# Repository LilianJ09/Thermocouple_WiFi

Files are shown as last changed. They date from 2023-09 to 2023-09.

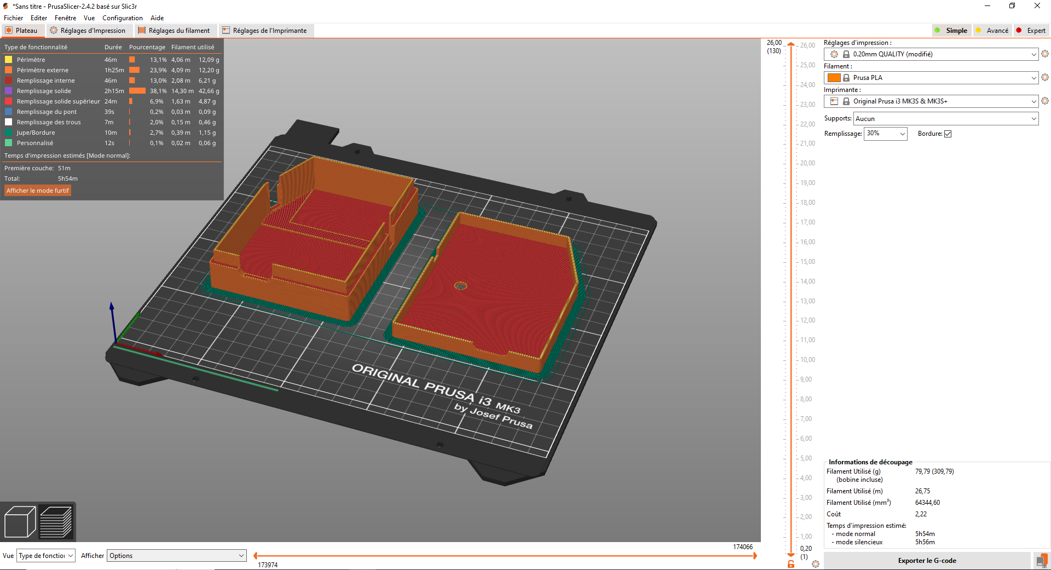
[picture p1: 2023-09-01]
CAD_modeling/prusa_slicer.PNG

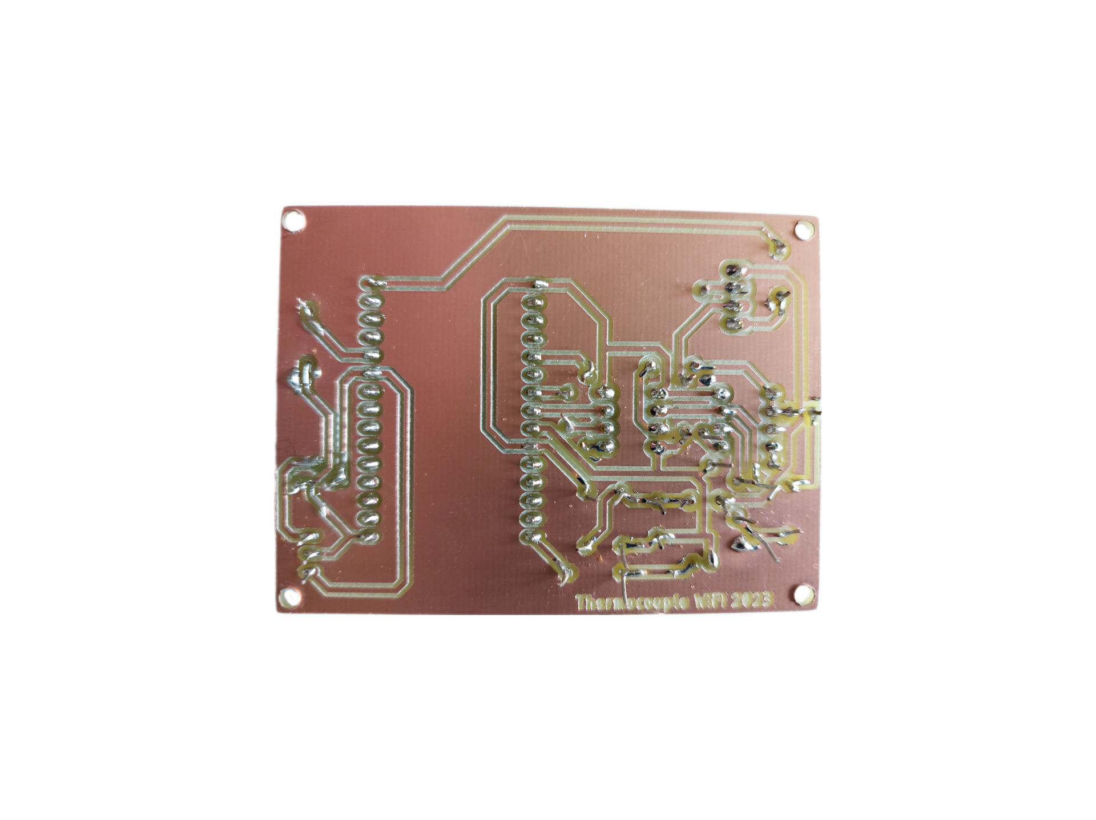
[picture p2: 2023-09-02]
Bank_pictures/Image-6.png

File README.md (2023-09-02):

# Thermocouple_WiFi
Developement of a kind K thermocouple with wireless data acquisition from an app.

The structure of the project is as follow :
  -Bank_pictures
  -CAD_modeling
  -App_thermocouple
    Throw the python file "Script_client-TCP" to start the App
  -Documents_produced

The components used are thoses : ESP8266 (nodeMCU), MCP3301, MCP6002 et LM335Z

JAOUANNE Lilian & GARCON Bastian

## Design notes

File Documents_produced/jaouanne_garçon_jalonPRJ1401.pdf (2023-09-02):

# PRJ1401 - THERMOCOUPLE

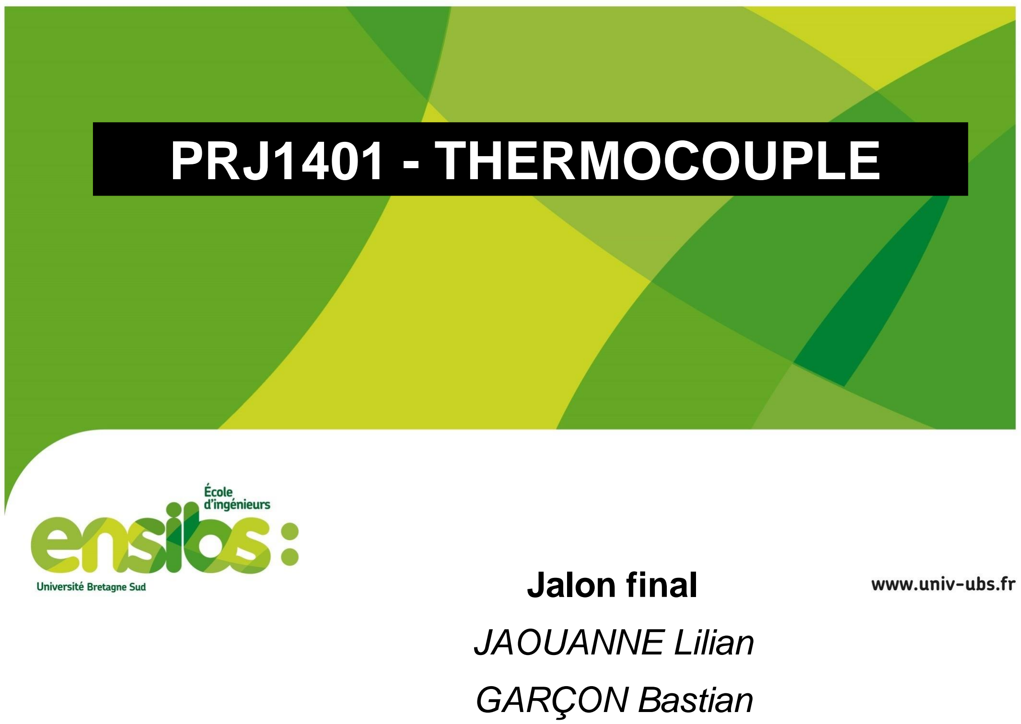
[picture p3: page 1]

Jalon final
JAOUANNE Lilian
GARÇON Bastian

# Cahier des charges

## - Plage de températures : -200 à 1200°C

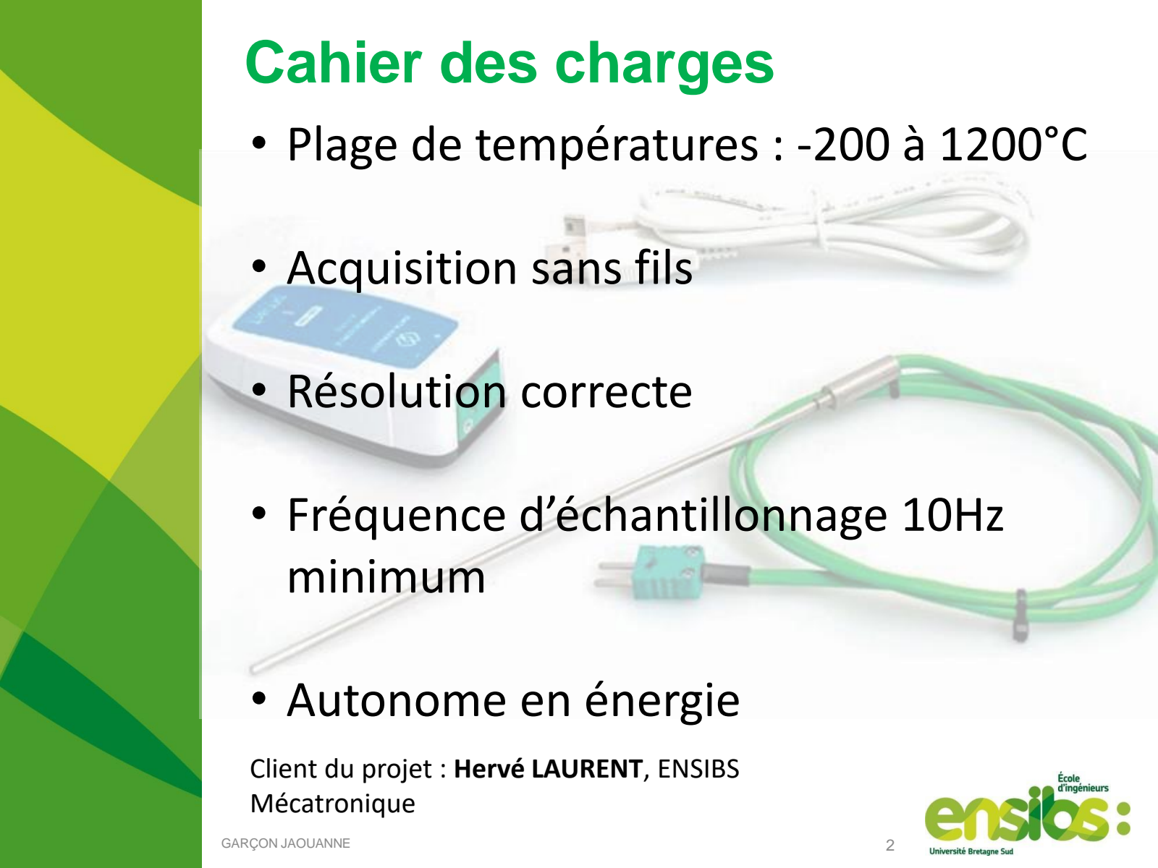
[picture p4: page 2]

GARÇON JAOUANNE | 2

Client du projet : Hervé LAURENT, ENSIBS Mécatronique

## - Acquisition sans fils

## - Résolution correcte

## - Fréquence d’échantillonnage 10Hz minimum

## - Autonome en énergie

# Où en étions nous ?

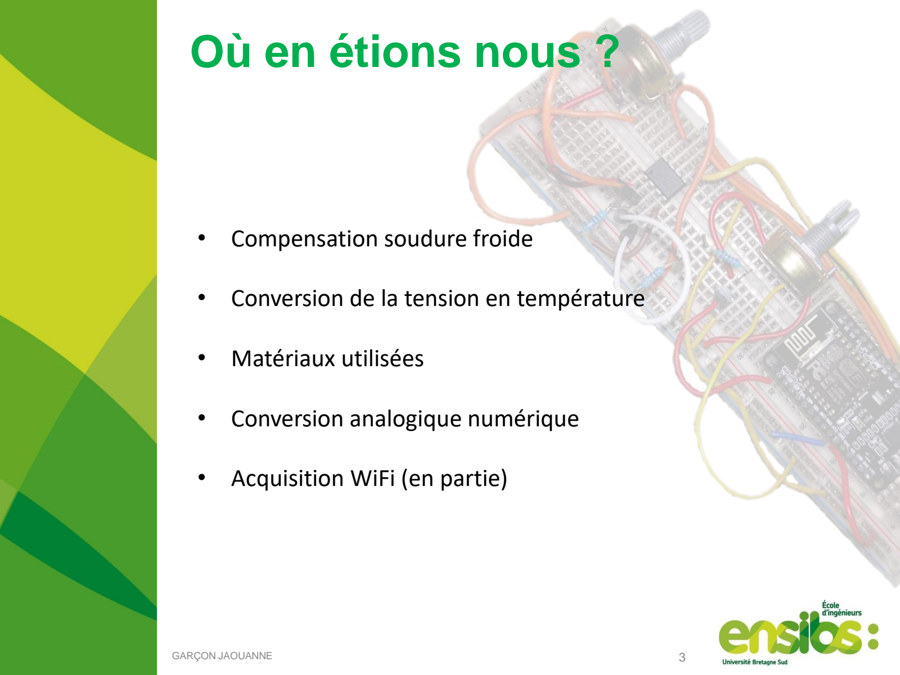
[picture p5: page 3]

- Compensation soudure froide
- Conversion de la tension en température
- Matériaux utilisées
- Conversion analogique numérique
- Acquisition WiFi (en partie)

# Ce que nous avons fait depuis

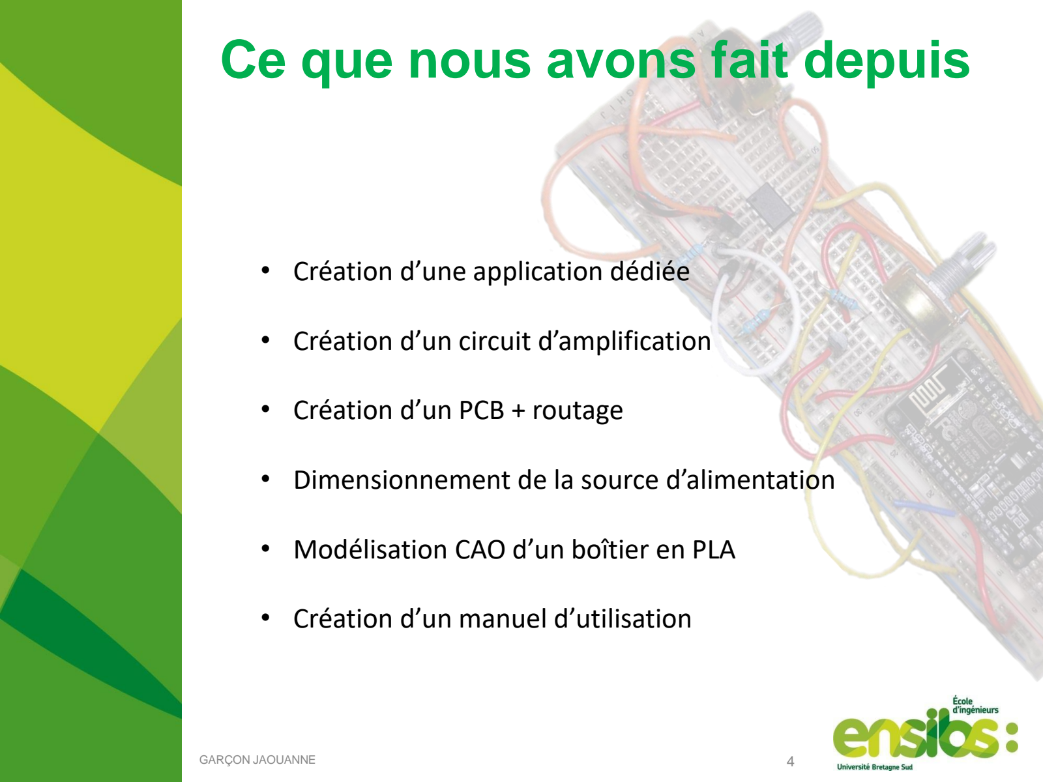
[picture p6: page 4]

- Création d’une application dédiée
- Création d’un circuit d’amplification
- Création d’un PCB + routage
- Dimensionnement de la source d’alimentation
- Modélisation CAO d’un boîtier en PLA
- Création d’un manuel d’utilisation

# Conversion tension / température

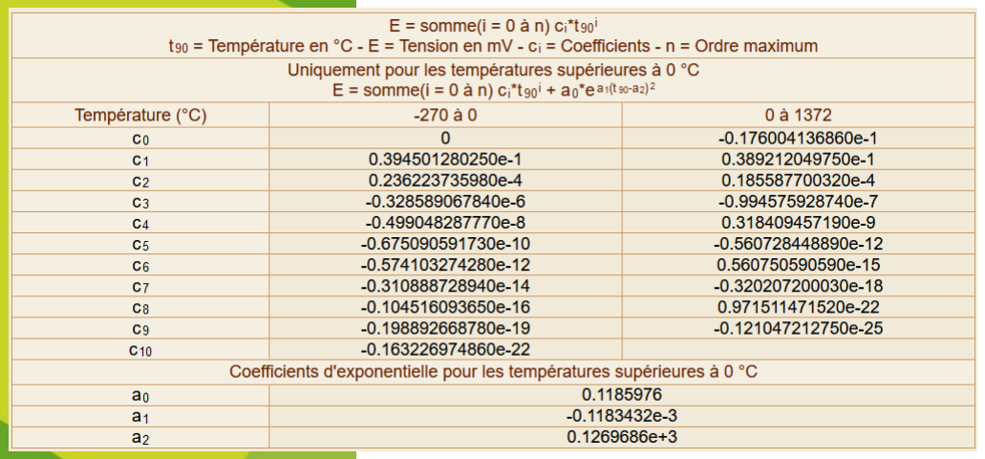
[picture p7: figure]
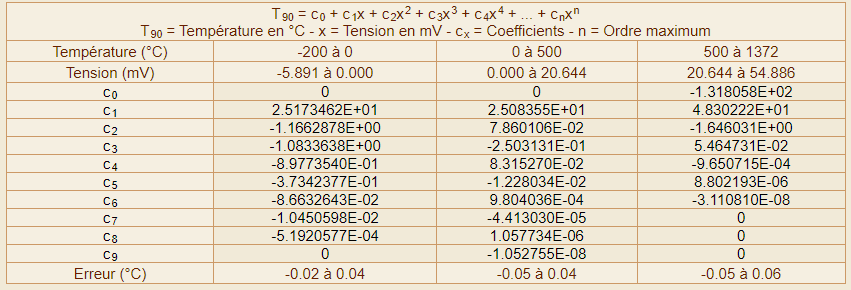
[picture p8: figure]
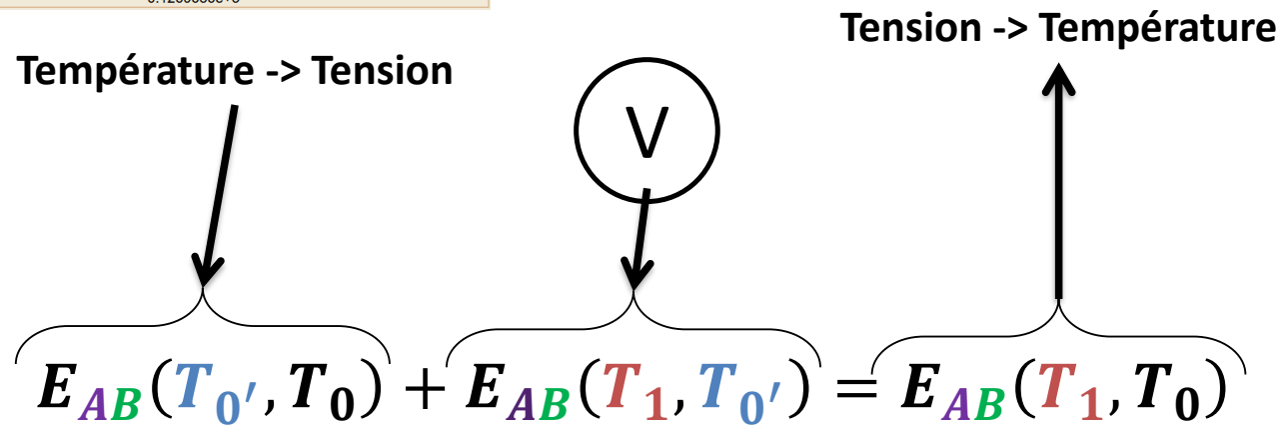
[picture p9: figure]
Température -> Tension; Tension -> Température; EAB T0; ′ , T0 + EAB T1, T0; = EAB T1, T0

# Matériaux utilisés

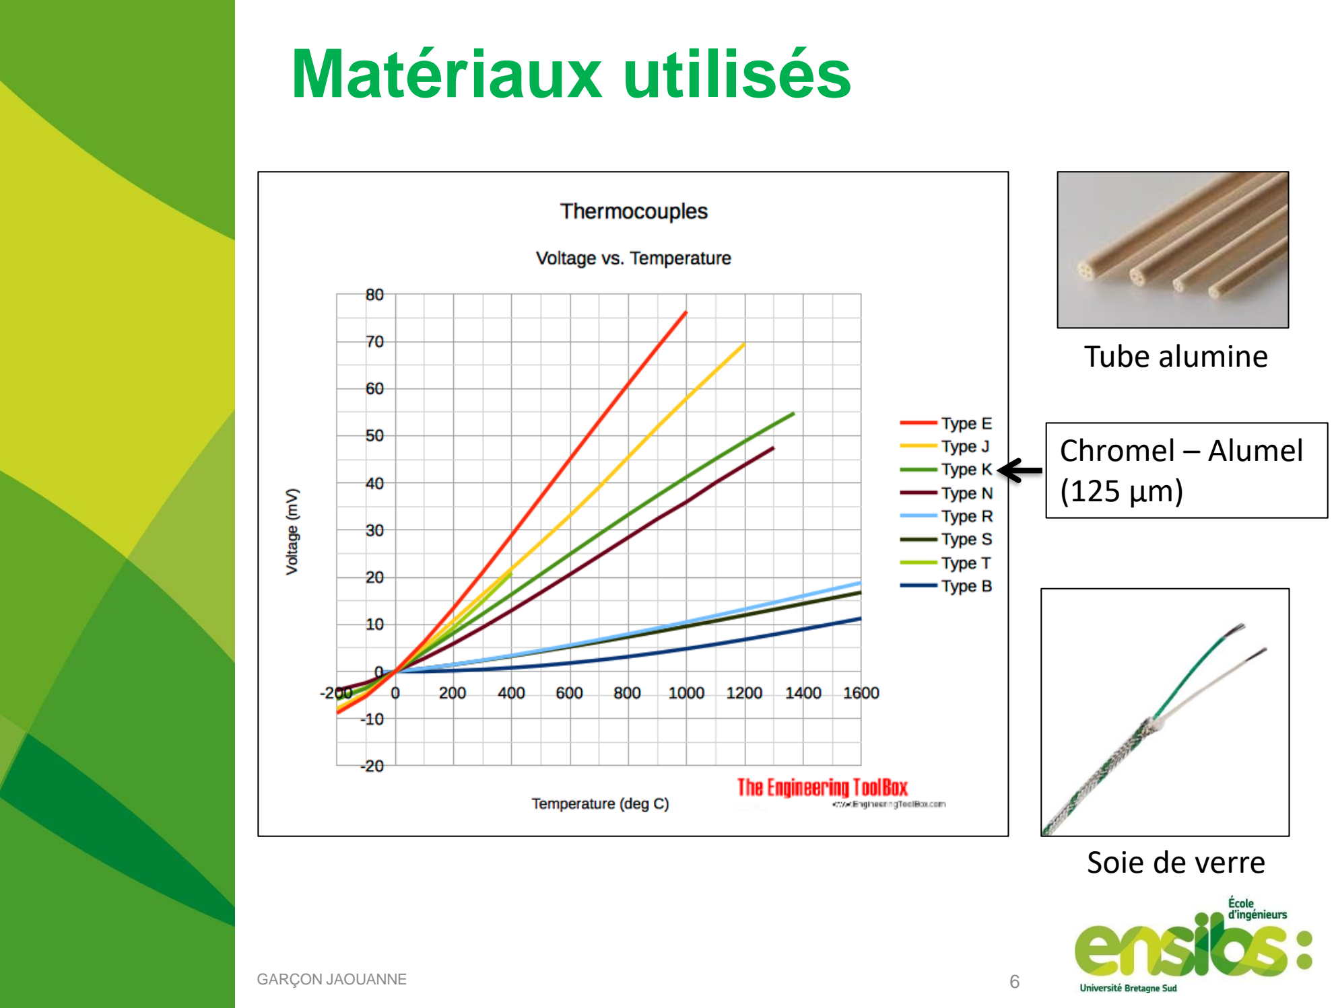
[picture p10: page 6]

Tube alumine

Soie de verre

Chromel – Alumel
(125 µm)

# Conversion analogique numérique MCP3301 13 bits

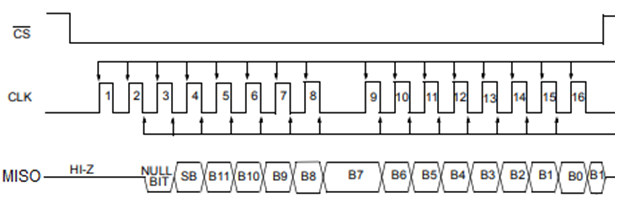
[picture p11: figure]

Mode de cadencement SPI : 0
- Polarité d’horloge (CPOL = 0) : Horloge en veille à l’état logique 0
- Phase d’horloge (CPHA = 0) : Cadencement des données sur le front montant

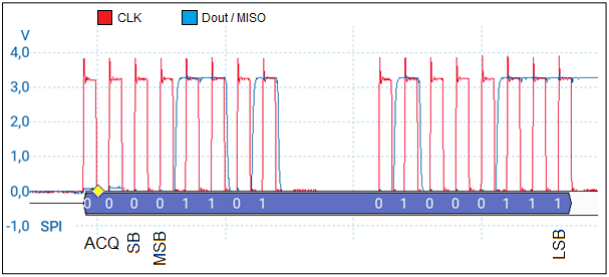
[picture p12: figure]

(0 0110 1010 0011)2S = 339910

Tension = 3399 × 1000 ×

Vref
4096

= 2738 mV, avec Vref = 3,3 V

# Conversion analogique numérique MCP3301 13 bits

# Acquisition WiFi

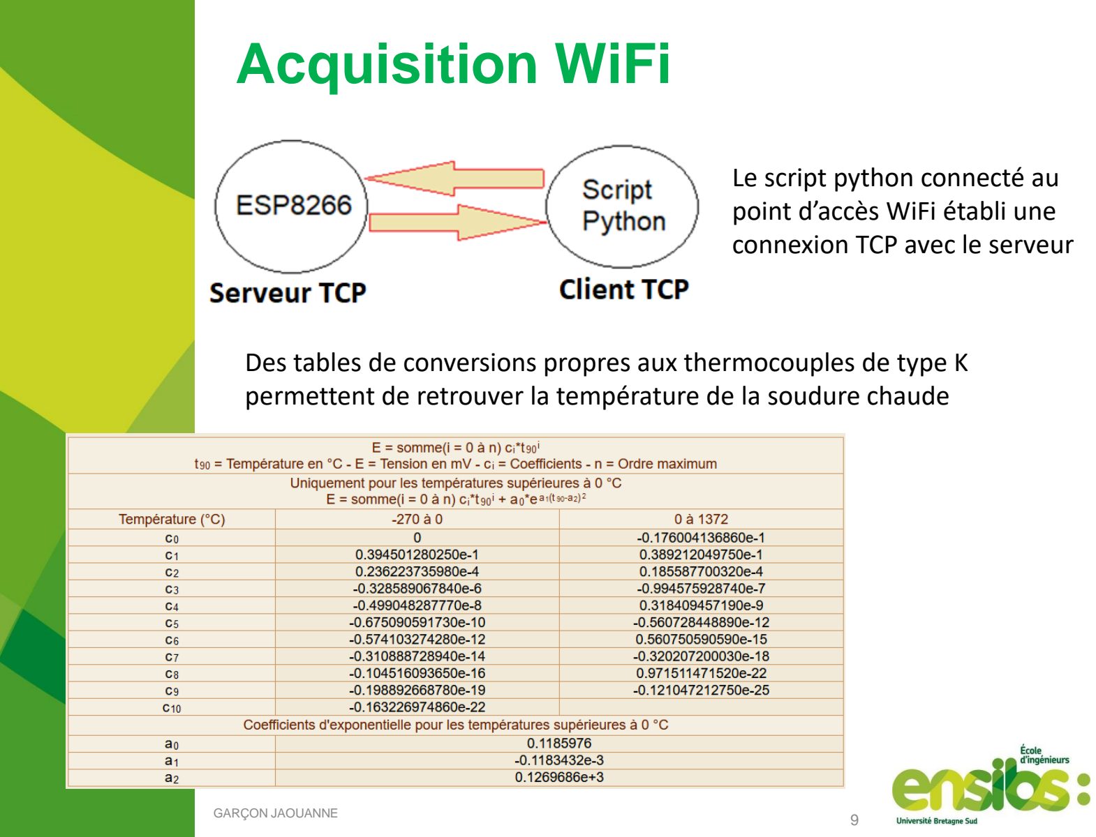
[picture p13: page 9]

Le script python connecté au point d’accès WiFi établi une connexion TCP avec le serveur

Des tables de conversions propres aux thermocouples de type K permettent de retrouver la température de la soudure chaude

# Application dédiée

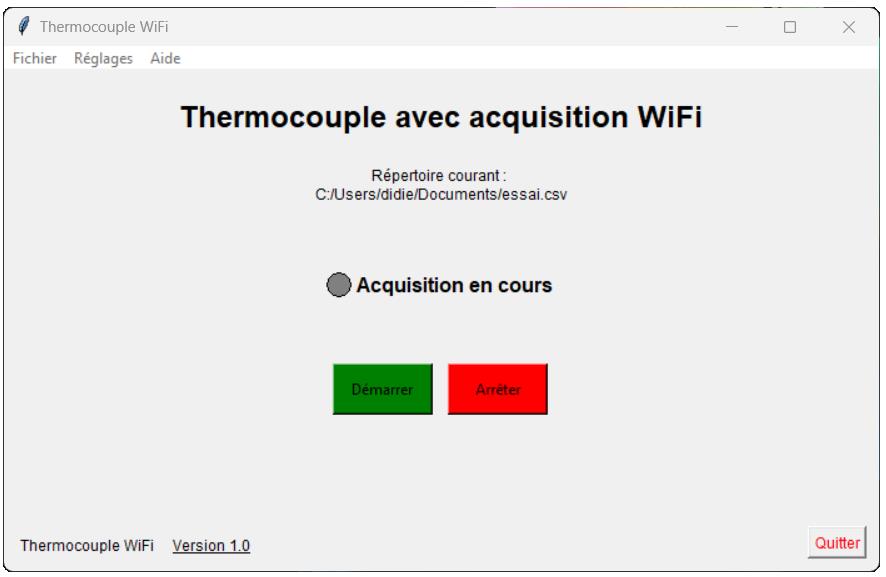
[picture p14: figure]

Icône application :

# Traitement des données

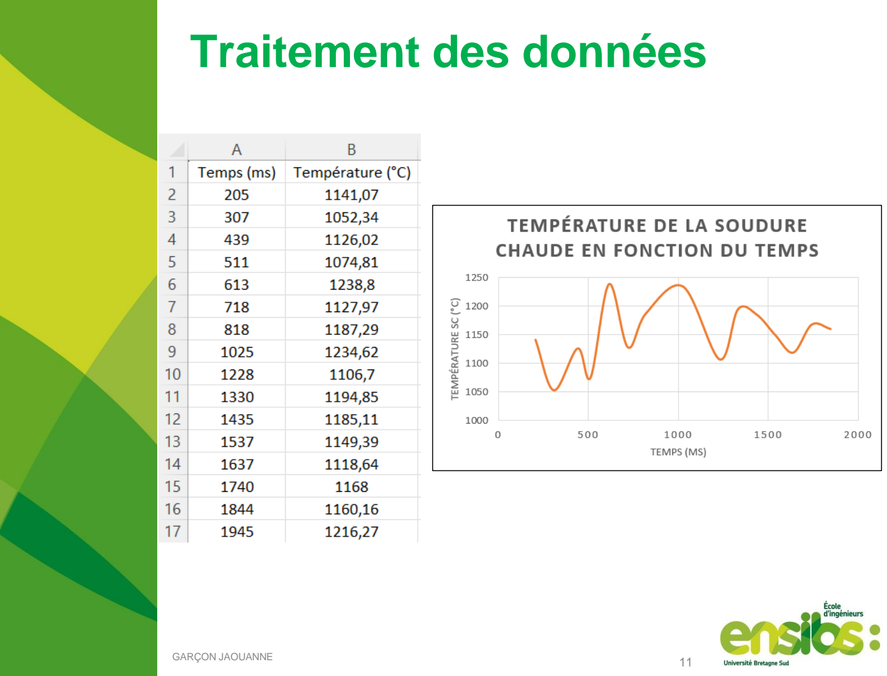
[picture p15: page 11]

# Amplification du signal MCP6002

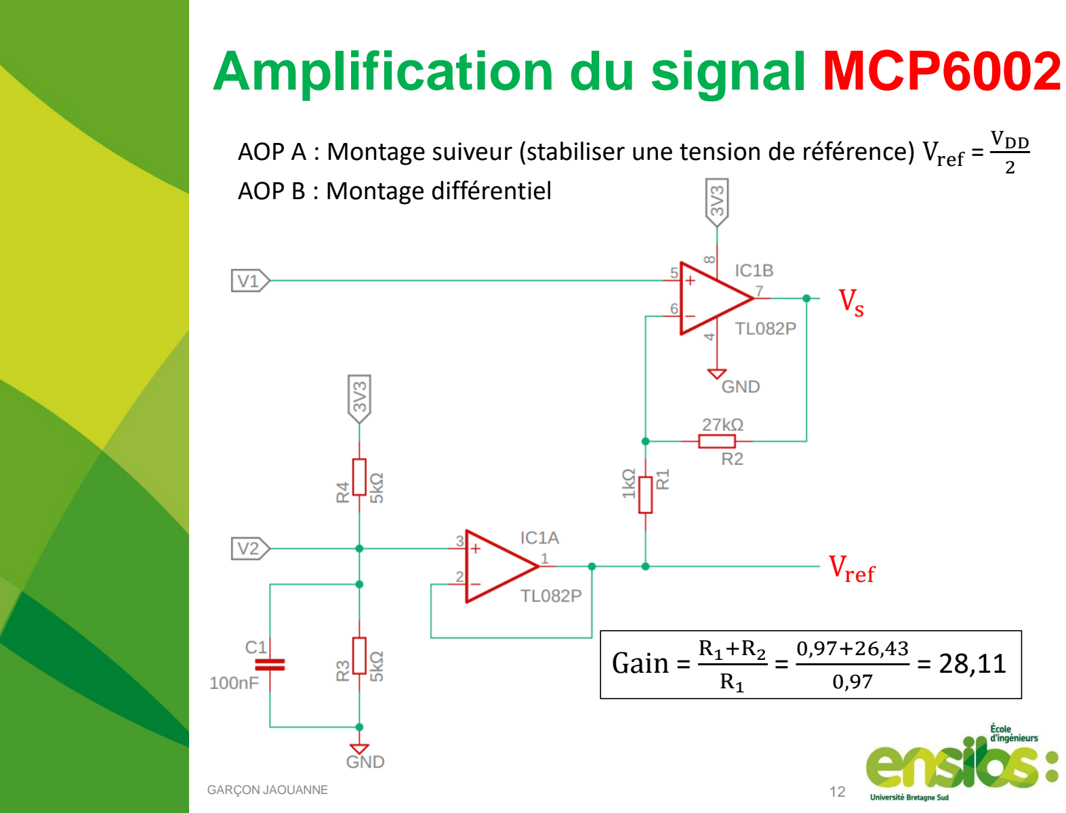
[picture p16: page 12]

AOP A : Montage suiveur (stabiliser une tension de référence) Vref =

VDD
2
AOP B : Montage différentiel

Gain =

R1+R2
R1

=

0,97+26,43
0,97

= 28,11

Vs

Vref

# Dimensionnement de l’alimentation

Pile AAA (Alcalines non rechargeables) Tension : 1,5 V
Capacité : 2500 mAh

3 piles AAA de 1,5 V en série ⇔ 4,5 V

Autonomie : ²⁵⁰⁰
| 300 ≈ 8h 30min

L’ESP8266 dispose d’un régulateur linéaire de tension vers 3,3 V Consommation 300 mA en mode point d’accès WiFi
(Le mode AP empêche les modes de veilles)

# Conception & routage PCB

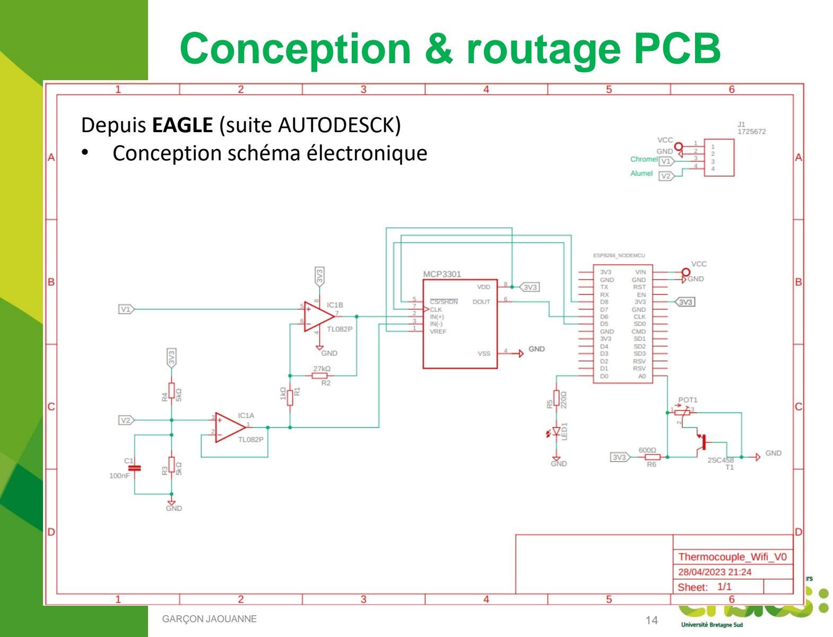
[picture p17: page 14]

Depuis EAGLE (suite AUTODESCK)
- Conception schéma électronique

# Conception & routage PCB

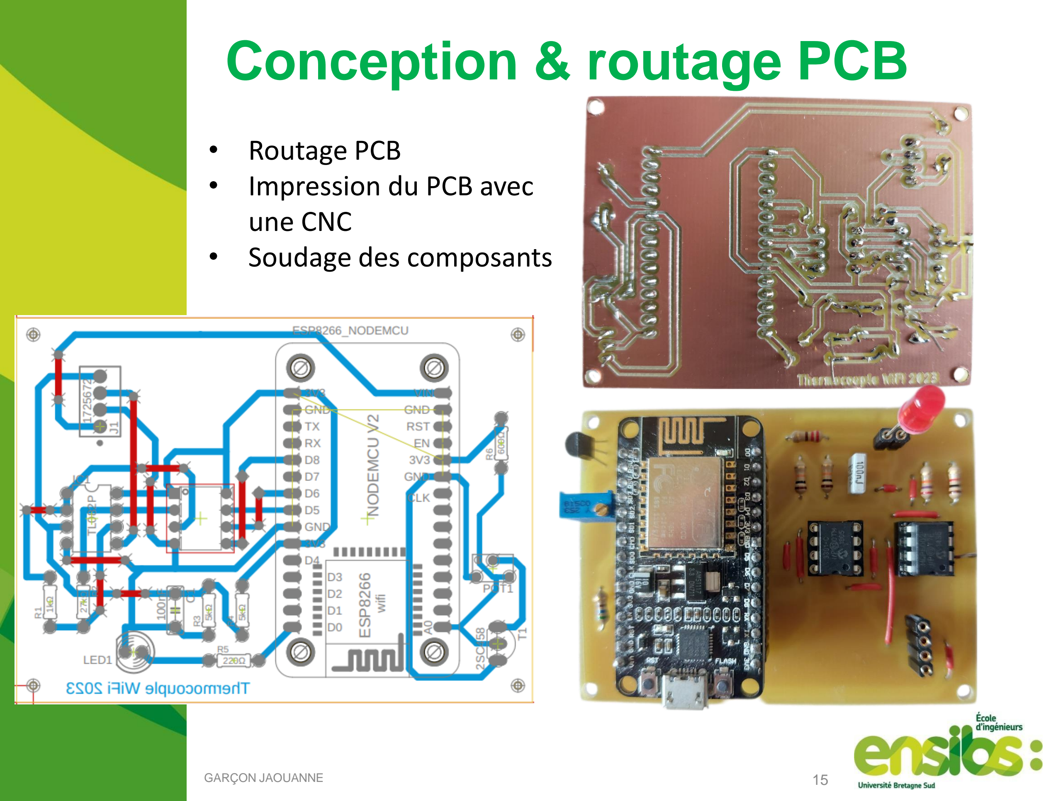
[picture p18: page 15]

- Routage PCB
- Impression du PCB avec
une CNC
- Soudage des composants

# Modélisation boitier

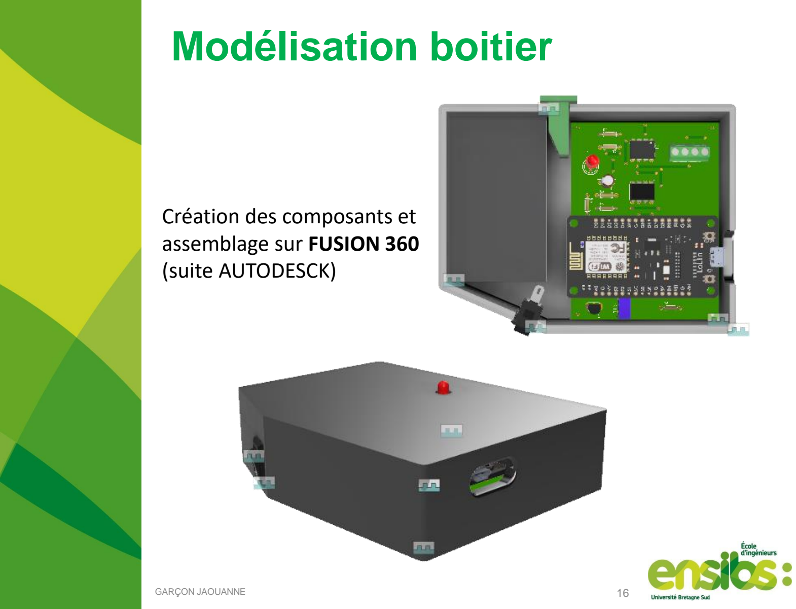
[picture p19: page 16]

Création des composants et assemblage sur FUSION 360
(suite AUTODESCK)

# Manuel d’utilisation

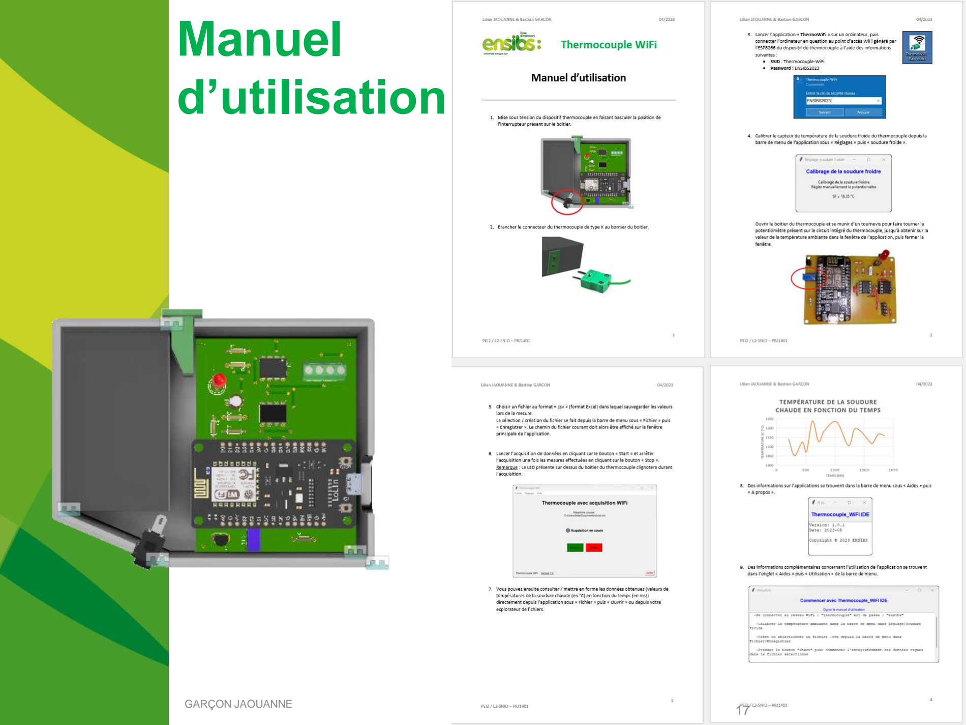
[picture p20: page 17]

# Eventuelles reprises du projet

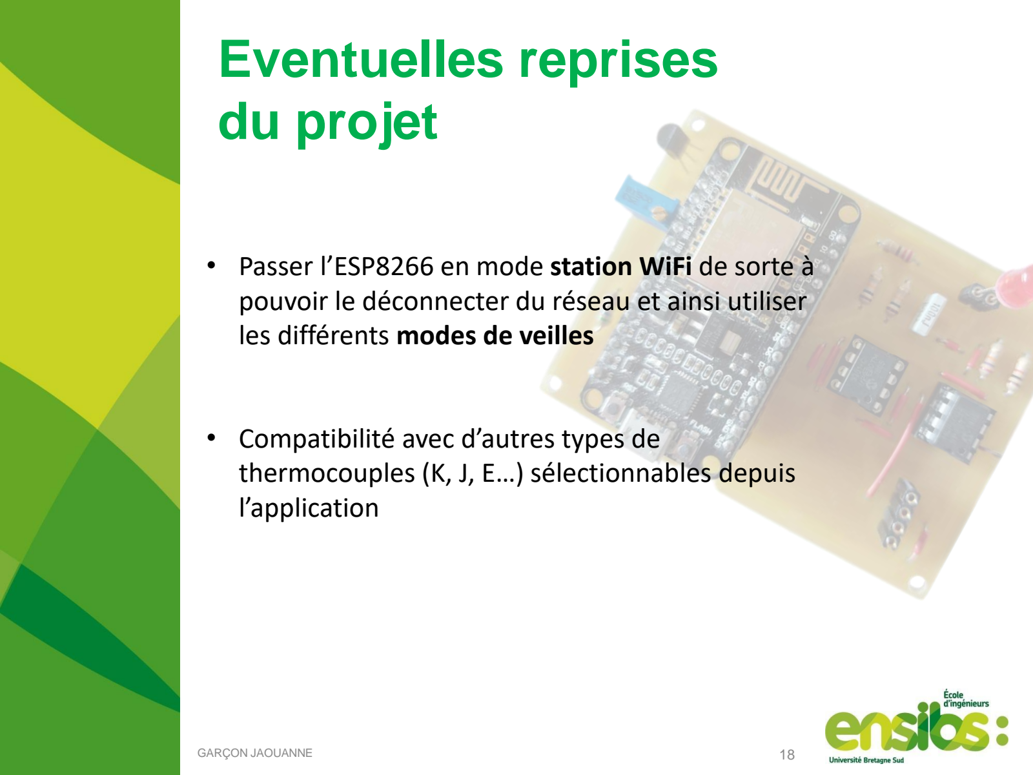
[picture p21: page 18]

- Passer l’ESP8266 en mode station WiFi de sorte à pouvoir le déconnecter du réseau et ainsi utiliser les différents modes de veilles
- Compatibilité avec d’autres types de thermocouples (K, J, E…) sélectionnables depuis l’application

# PRJ1401 - THERMOCOUPLE

Jalon final
JAOUANNE Lilian
GARÇON Bastian

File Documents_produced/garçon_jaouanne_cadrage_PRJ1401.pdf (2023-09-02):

JAOUANNE Lilian GARÇON Bastian | 13 janvier 2023
L2 SNIO / PEI2 | 1

## PRJ 1404

### GARÇON Bastian & JAOUANNE Lilian

### Client : LAURENT Hervé

__________________________________________________________________________________

## Table des matières

## Objectif :

L’objet de ce projet consiste à développer un thermocouple et d’acquérir la valeur de la température par un moyen sans fil (Bluetooth, Wifi…) sur une centrale d’acquisition. Le thermocouple devra pouvoir fonctionner sur une plage de température de -200 à 1200°C.

Bien que ce type de thermocouple existe déjà sur le marché, il nous ait demandé d’en concevoir un à partir des moyens disponibles à l’ENSIBS et si possible à bas coût.

# Thermocouple Document de cadrage

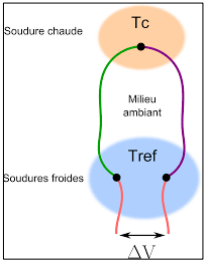
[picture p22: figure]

L2 SNIO / PEI2 | 2

## Fonctionnement du thermocouple :

Le principe du thermocouple consiste à mesurer une différence de potentiel entre deux fils constitués de deux conducteurs différents et soudés entre eux à une extrémité.

La mesure s’effectue ponctuellement au niveau de la soudure (nommée soudure chaude ou jonction de référence).

Un thermocouple est un capteur actif de température. Il est composé de deux jonctions reliant deux métaux ou alliages différents. Le thermocouple fonctionne grâce à l’effet Seebeck (Cf Bibliographie) qui produit un courant continu lorsqu'il y a une différence de température entre les deux jonctions. En ouvrant le circuit, on mesure une force électromotrice (tension) de faible niveau, mais mesurable (centaine de µV). Le thermocouple mesure la différence de température entre le point de mesure (SF – soudure froide) et le point de raccordement (SC – soudure chaude).

Pour s'assurer que la température ambiante aux bornes de raccordement de la soudure froide (idéalement 0°C) n'affecte pas le résultat de la mesure, une compensation de soudure froide est nécessaire.

La tolérance d’un thermocouple est généralement de ± 1°C. La soudure chaude peut être générée à partir d’un arc électrique et les fils qui composent le thermocouple (ou câbles d'extension/compensation) ont une couleur caractéristique normalisée. Le conducteur négatif est toujours blanc, le conducteur positif est toujours de la couleur de la gaine. Chaque paire de conducteurs définit une plage de mesure et un graphe associé, nommé par une lettre.

Figure 1 : Principe du thermocouple

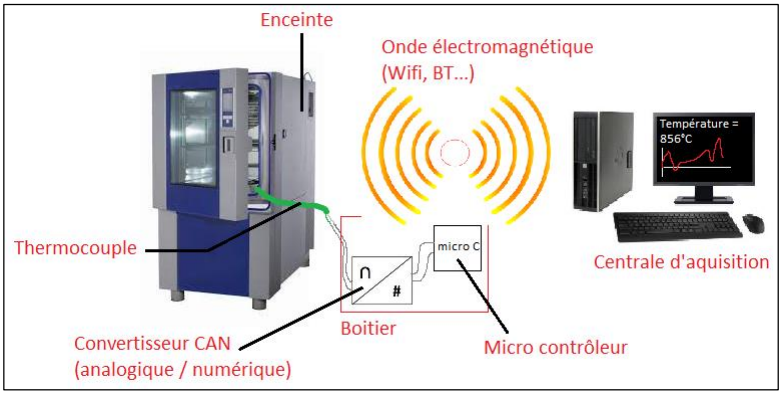
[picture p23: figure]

L2 SNIO / PEI2 | 3

## Cahier des charges :

Figure 2 : Schéma du dispositif envisagé

- Thermocouple

Il existe différents types de thermocouples suivant la plage de température à mesurer, différenciant le couple de matériaux semi-conducteurs à utiliser.

Nous prendrons un thermocouple de type K pour des températures allant de -270 à 1370°C avec une sensibilité de 41µV/°C. Le type K demande un fil de Chromel (alliage de Nickel et de Chrome) et un fil d’Alumel (alliage de Nickel et d’Aluminium).

La taille des 2 fils utilisés influencera sur la vitesse et la précision des mesures. Nous préférerons donc des fils fins et prendrons des fils de 250 microns.

Pour isoler électriquement nos deux fils, nous utiliserons un tube d’alumine (minéraux de température de fusion 2000°C) pour la partie à l’intérieur de l’enceinte et une isolation en soie de verre pour la partie des fils à l’extérieur (fusion à 300°C).

Pour compenser la température de référence de la soudure froide, il est nécessaire de connaître la température de la jonction de référence. On utilisera pour cela une thermistance CTN ou autre capteur de température.

- Moyen d’acquisition

Pour le traitement du signal, il faudra un convertisseur analogique numérique (choisi en fonction de son nombre de bits) ou d’un module de récupération directe de la température devant renvoyer la donnée mesurée à un microcontrôleur. Microcontrôleur qui devra ensuite pouvoir traiter la différence

L2 SNIO / PEI2 | 4

de potentiel et la température de la jonction de mesure, puis transmettre la donnée par Bluetooth ou Wifi à un moyen d’acquisition (poste informatique, smartphone…).

La centrale d’acquisition devra ensuite récupérer la donnée émise et gérer son affichage.

Une solution serait le développement d’une application avec un script Python, affichant des informations sur la série de mesures dans le terminal par exemple.

- Autonomie

L’ensemble devra avoir sa propre source d’alimentation, il ne devra pas être relié à un secteur d’alimentation. De plus, le moyen d’alimentation devra assurer une durée de fonctionnement correct et répondre aux impulsions de consommations importantes demandées par le Bluetooth et le Wifi.

- Design

L’ensemble devra avoir une ergonomie compacte et discrète. Les fils du thermocouple sortiront de l’enceinte isolée thermiquement et être reliés à un boîtier situé à côté de l’enceinte (à l’extérieur). Boitier possiblement imprimé en 3D avec du PLA, dans lequel se trouveront les composants propres au traitement et à l’émission du signal.

L2 SNIO / PEI2 | 5

## Ressource et personnel mis à notre disposition

### Ressources

Pour ce projet, nous pourrons utiliser les différents outils présents au sein de l’ENSIBS de Lorient notamment ceux se trouvant dans le laboratoire de mécatronique. Si nécessaire, nous devrons être supervisés par un enseignant lors de l’utilisation de ces derniers.

Pour le matériel, nous pourrons prélever les composants prévus à cet effet, pour la fabrication de notre thermocouple à l’ENSIBS.

Enfin, si le matériel n’est pas disponible au sein de l’école. Nous pourrons en commander sur les sites partenaires.

### Personnel

Lors de ce projet, nous pourrons aussi nous référer à différentes personnes spécialistes dans leur domaine afin d’obtenir des précisions sur différents sujets. Cela a déjà été le cas avec l’un des chercheurs au LAB-STICC, William BERCKMANS. William est un spécialiste des thermocouples. Il nous a donc éclairé pour la conception de celui-ci (épaisseur des fils, choix du matériau, soudage…) et nous aussi déjà donné du matériel (lecteur de thermocouple et câbles de thermocouple) pour débuter notre projet.

Quant à notre tuteur Hervé LAURENT, un mail lui sera envoyé après chaque session de projet. Avec à l’intérieur quelques phrases sur ce que nous avons fait durant la séance, mais aussi ce qu’il nous reste à faire pour les séances à venir. Quelquesrendez-vous seront aussi pris avec Hervé afin de faire le point sur l’avancement du projet.

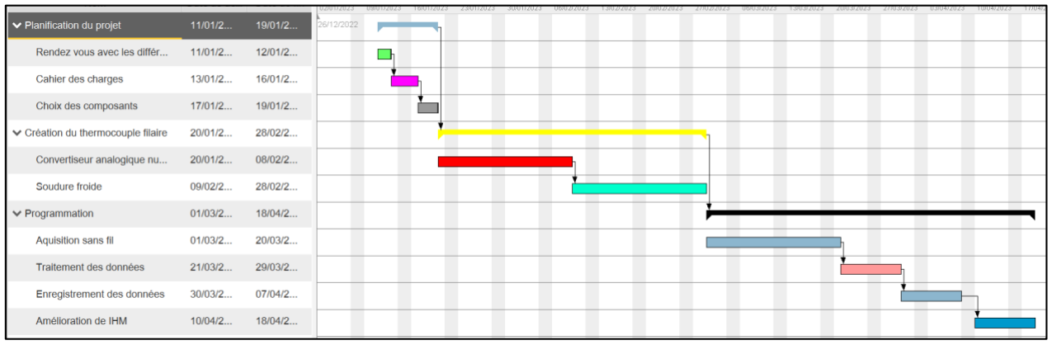
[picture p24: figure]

L2 SNIO / PEI2 | 6

## Calendrier

date | événement du projet
lundi 12 décembre | début de la diffusion des sujets
vendredi 6 janvier | présentation du fonctionnement et des sujets
lundi 9 janvier | retour et diffusion des affectations étudiants/projets
vendredi 13 janvier | première séance de projet
vendredi 13 janvier | fin prises de rendez-vous et rencontre avec les tuteurs
vendredi 20 janvier | dépôt du document de Cadrage
vendredi 10 mars | dépôt diaporama du jalon
semaine 11 | jalon
vendredi 5 mai | dépôt diaporama de la soutenance
semaine 19 | soutenance
vendredi 12 mai | dépôt du rapport
vendredi 12 mai | dépôt de l’archive de reprise du projet

Tableau 1 : calendrier du projet

Figure 3 : Planification du projet fait sur GanttProject

L2 SNIO / PEI2 | 7

## Bibliographie

- EFFET SEEBECK
https://fr.wikipedia.org/wiki/Effet_Seebeck
- THERMOCOUPLE
https://fr.wikipedia.org/wiki/Thermocouplehttps://youtu.be/7QFdb2aJn14

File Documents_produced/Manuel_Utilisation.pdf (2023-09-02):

Lilian JAOUANNE & Bastian GARCON | 04/2023

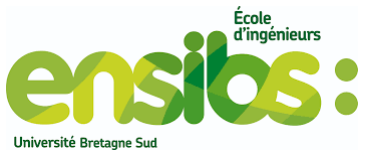
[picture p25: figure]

PEI2 / L2-SNIO – PRJ1401

# Manuel d’utilisation

1. Mise sous tension du dispositif thermocouple en faisant basculer la position de l’interrupteur présent sur le boitier.

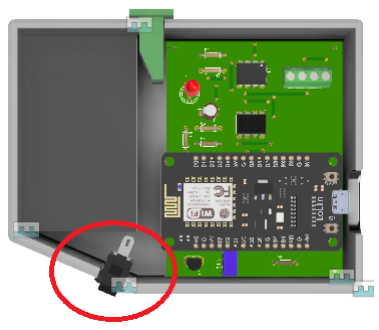
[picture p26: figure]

2. Brancher le connecteur du thermocouple de type K au bornier du boitier.

# Thermocouple WiFi


3. Lancer l’application « ThermoWiFi » sur un ordinateur, puis connecter l’ordinateur en question au point d’accès WiFi généré par l’ESP8266 du dispositif du thermocouple à l’aide des informations suivantes :
- SSID : Thermocouple-WiFi
- Password : ENSIBS2023


4. Calibrer le capteur de température de la soudure froide du thermocouple depuis la barre de menu de l’application sous « Réglages » puis « Soudure froide ».


Ouvrir le boitier du thermocouple et se munir d’un tournevis pour faire tourner le potentiomètre présent sur le circuit intégré du thermocouple, jusqu’à obtenir sur la valeur de la température ambiante dans la fenêtre de l’application, puis fermer la fenêtre.


5. Choisir un fichier au format « csv » (format Excel) dans lequel sauvegarder les valeurs lors de la mesure.
La sélection / création du fichier se fait depuis la barre de menu sous « Fichier » puis « Enregistrer ». Le chemin du fichier courant doit alors être affiché sur la fenêtre principale de l’application.
6. Lancer l’acquisition de données en cliquant sur le bouton « Start » et arrêter l’acquisition une fois les mesures effectuées en cliquant sur le bouton « Stop ». Remarque : La LED présente sur dessus du boitier du thermocouple clignotera durant l’acquisition.


7. Vous pouvez ensuite consulter / mettre en forme les données obtenues (valeurs de températures de la soudure chaude (en °C) en fonction du temps (en ms)) directement depuis l’application sous « Fichier » puis « Ouvrir » ou depuis votre explorateur de fichiers.


8. Des informations sur l’applications se trouvent dans la barre de menu sous « Aides » puis « A propos ».
9. Des informations complémentaires concernant l’utilisation de l’application se trouvent dans l’onglet « Aides » puis « Utilisation » de la barre de menu.

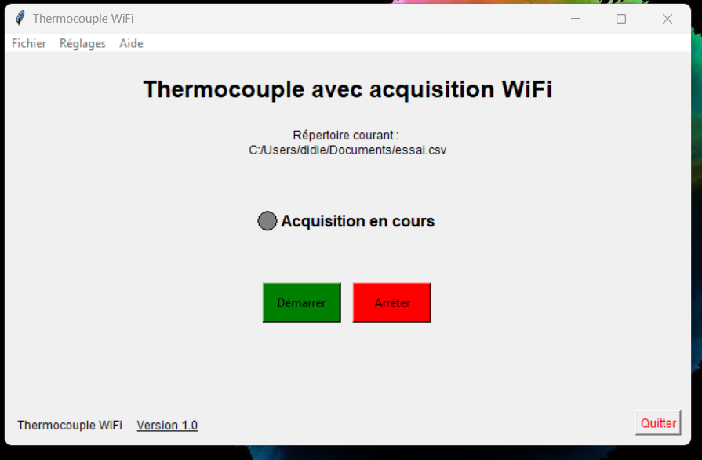
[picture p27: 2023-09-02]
Bank_pictures/IHM_App.png

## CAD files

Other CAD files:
CAD_modeling/Boitier_Thermocouple.SLDDRW
CAD_modeling/Couvercle_Thermocouple.SLDDRW
CAD_modeling/Couvercle_Thermocouple.ipt

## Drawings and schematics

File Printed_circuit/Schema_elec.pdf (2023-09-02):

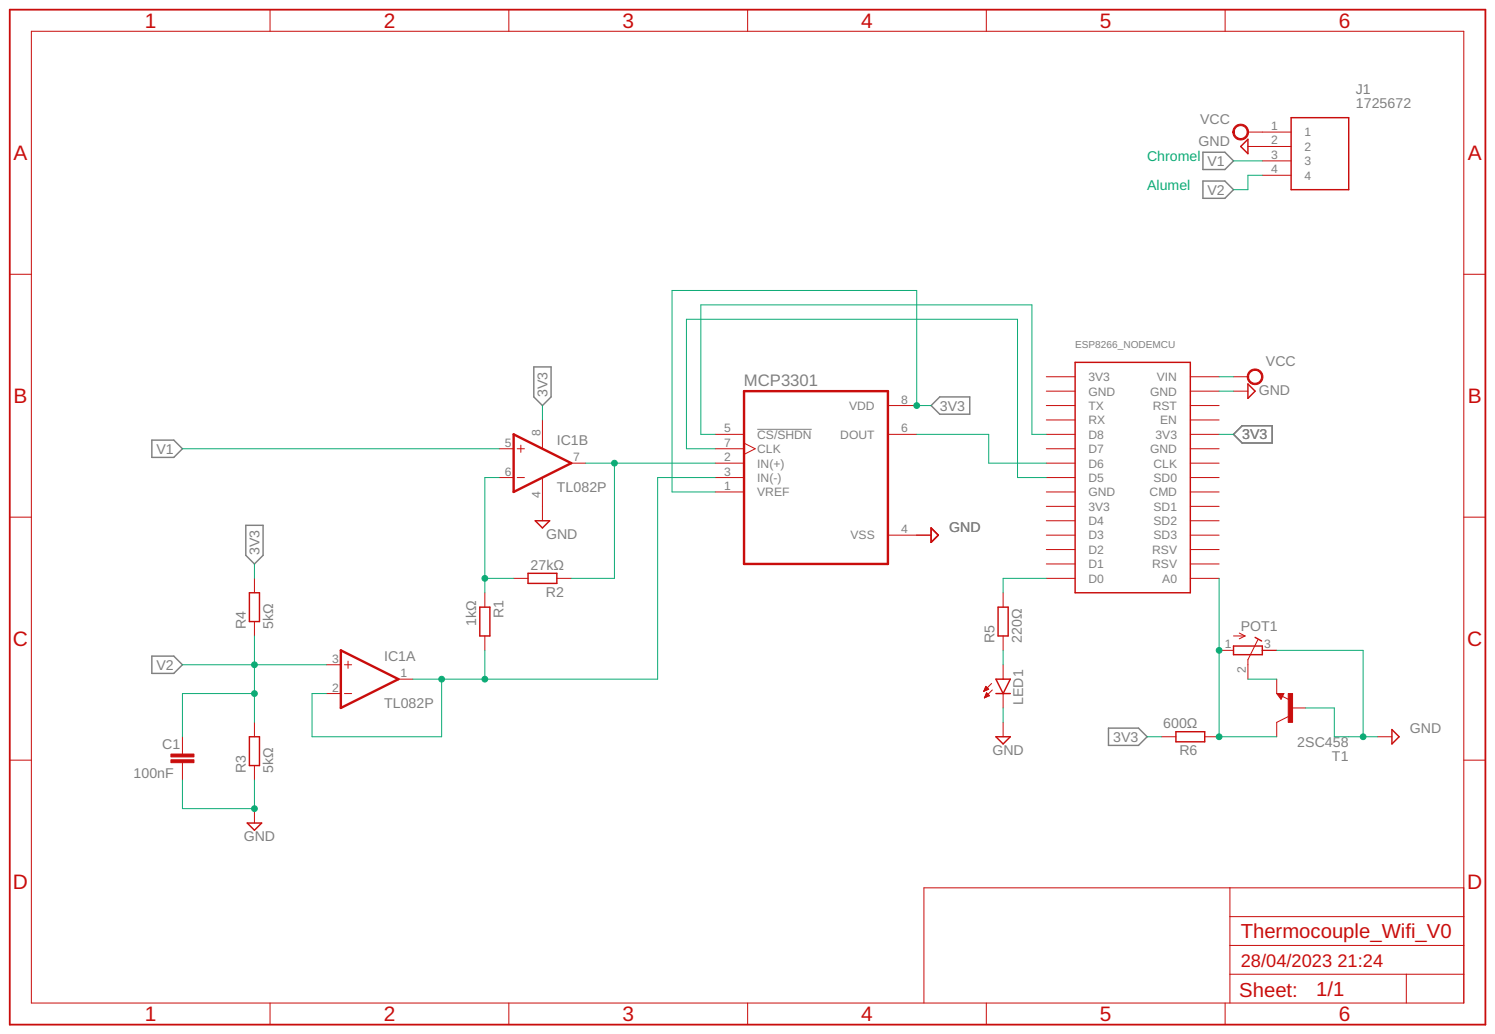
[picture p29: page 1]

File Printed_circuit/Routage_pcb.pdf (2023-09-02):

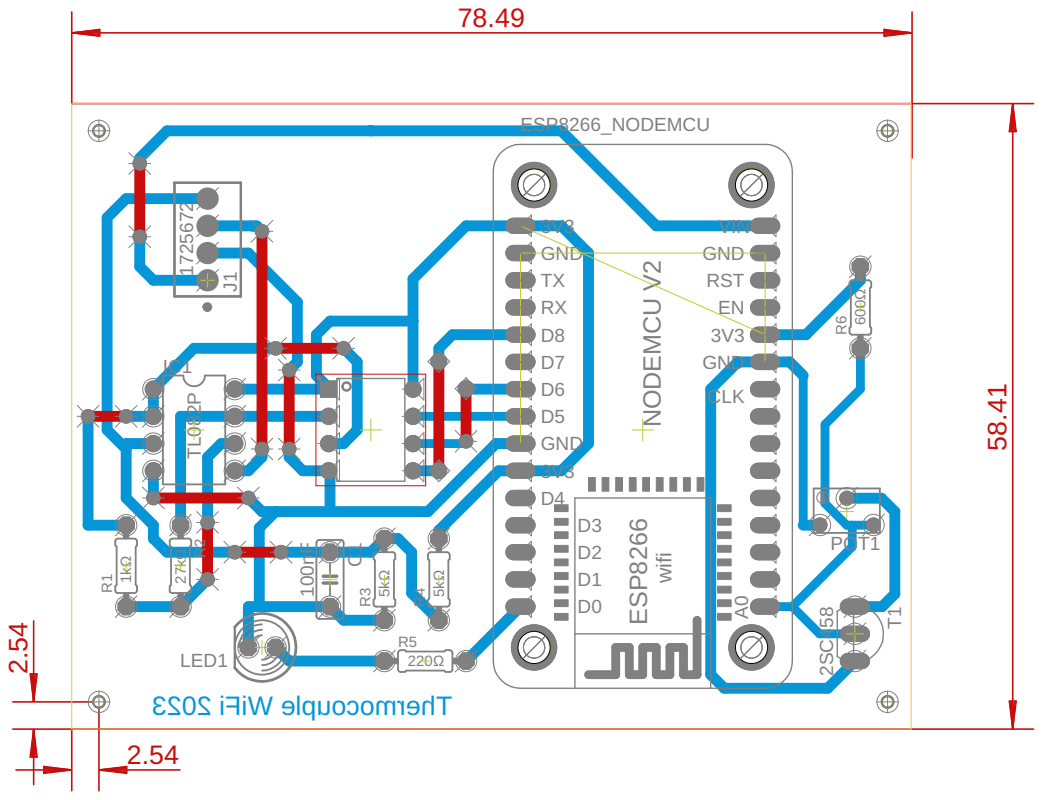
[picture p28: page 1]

3202i Fi Wel puoco mr ehT78.49 58.41 2.54 2.54ESP8266 wifi NODEMCU V2 3V3 GND TXRXD8 D7 D6 D5 GND 3V3 D4 D3 D2 D1 D0 A0 VIN GND RST EN 3V3 GND CLK ESP8266_NODEMCU J1 LED1 POT1 R6 R5 IC1 R2 R1 R4 R3 C1 T1 1725672 600Ω 220Ω TL082P 27kΩ 1kΩ 5kΩ 5kΩ 100nF 2SC458
